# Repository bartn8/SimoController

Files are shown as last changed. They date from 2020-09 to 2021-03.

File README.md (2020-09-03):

# SimoController
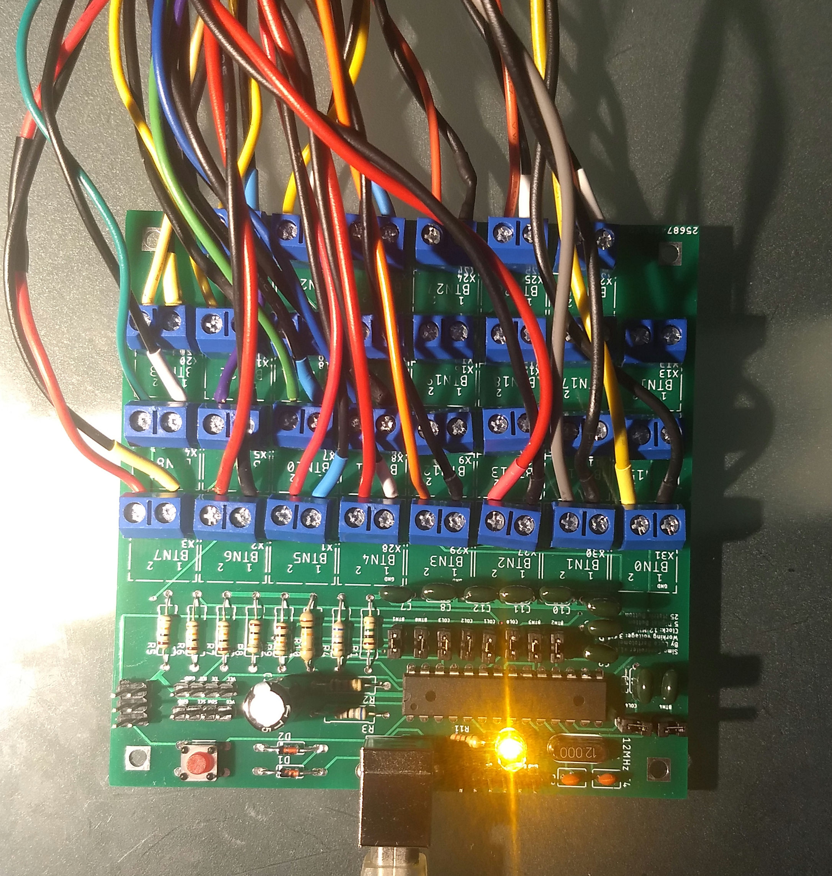
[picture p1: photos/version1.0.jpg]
Image of the Board

## An ATMEGA328P based gamepad controller

- **5 Digital buttons** (first two can be used as Analog pins)
- **25 Matrix buttons**
- **Gamepad HID Device**: four axis and 22 buttons for single gamepad or two axis and 11 buttons for double gamepad

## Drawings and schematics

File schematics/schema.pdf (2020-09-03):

# ATMEGA168-20PICSP

4u7

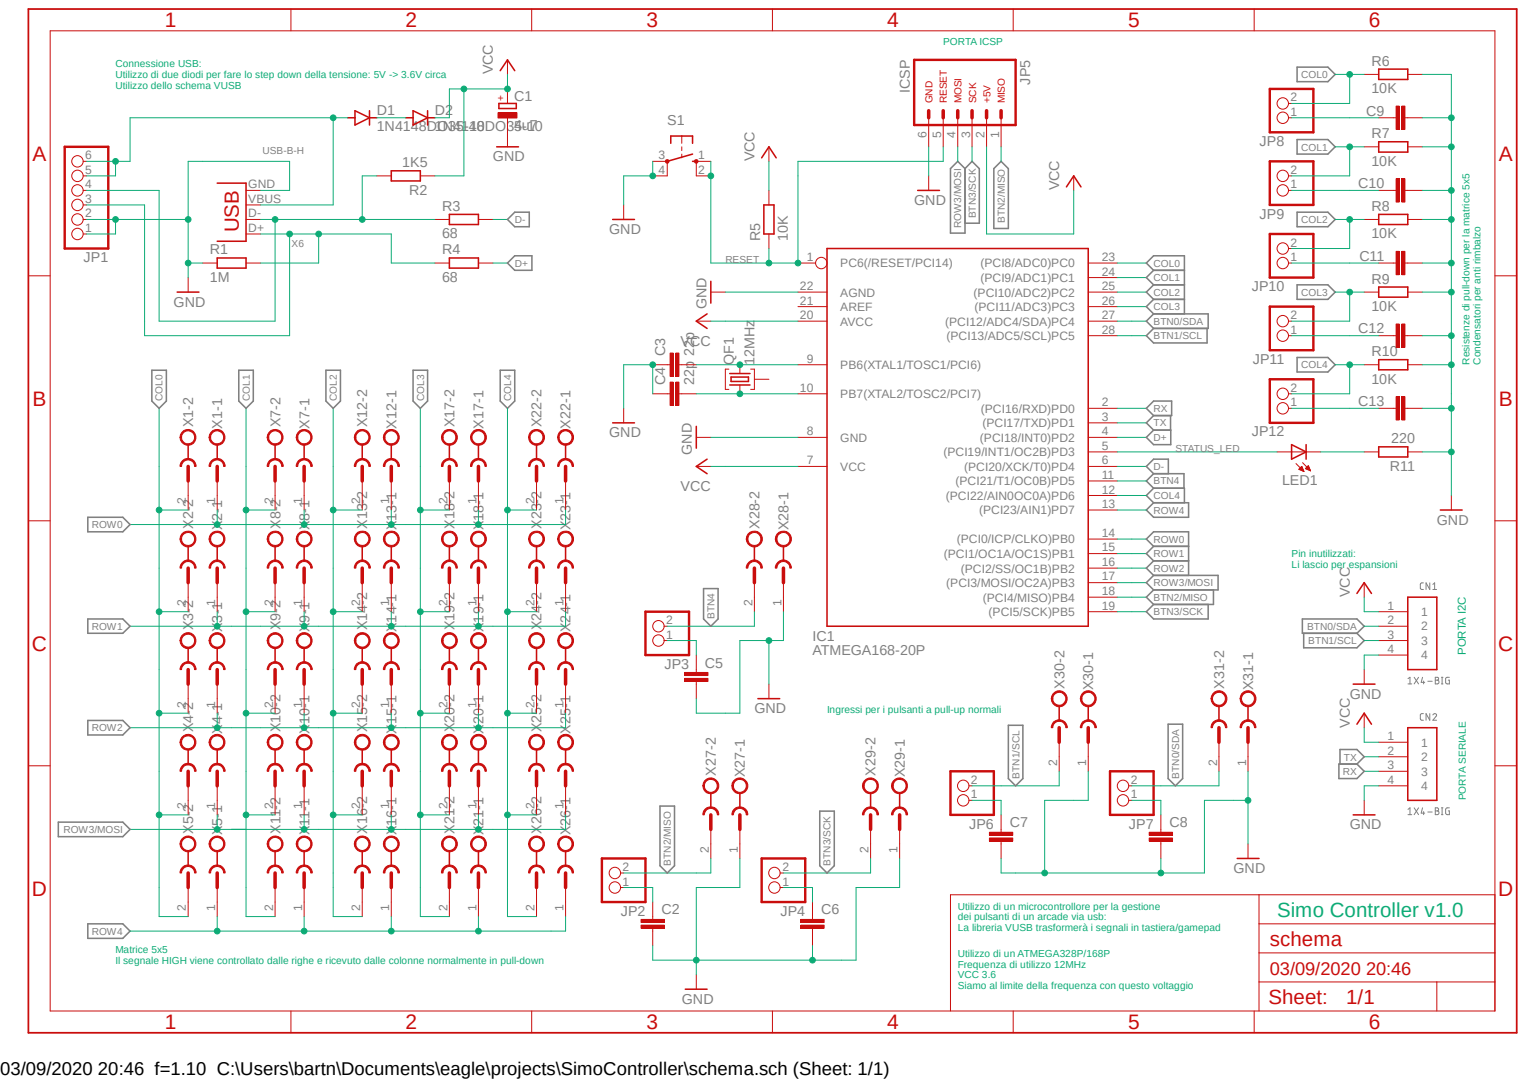
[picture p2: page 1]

Connessione USB:
Utilizzo di due diodi per fare lo step down della tensione: 5V -> 3.6V circa
Utilizzo dello schema VUSB

+GND RESET MOSI SCK +5V MISO USB

Pin inutilizzati:
Li lascio per espansioni

Ingressi per i pulsanti a pull-up normali

dei pulsanti di un arcade via usb: Frequenza di utilizzo 12MHz VCC 3.6 Siamo al limite della frequenza con questo voltaggio | Simo Controller v1.0 Utilizzo di un microcontrollore per la gestione

Sheet: 1/1

03/09/2020 20:46 f=1.10 C:\Users\bartn\Documents\eagle\projects\SimoController\schema.sch (Sheet: 1/1)

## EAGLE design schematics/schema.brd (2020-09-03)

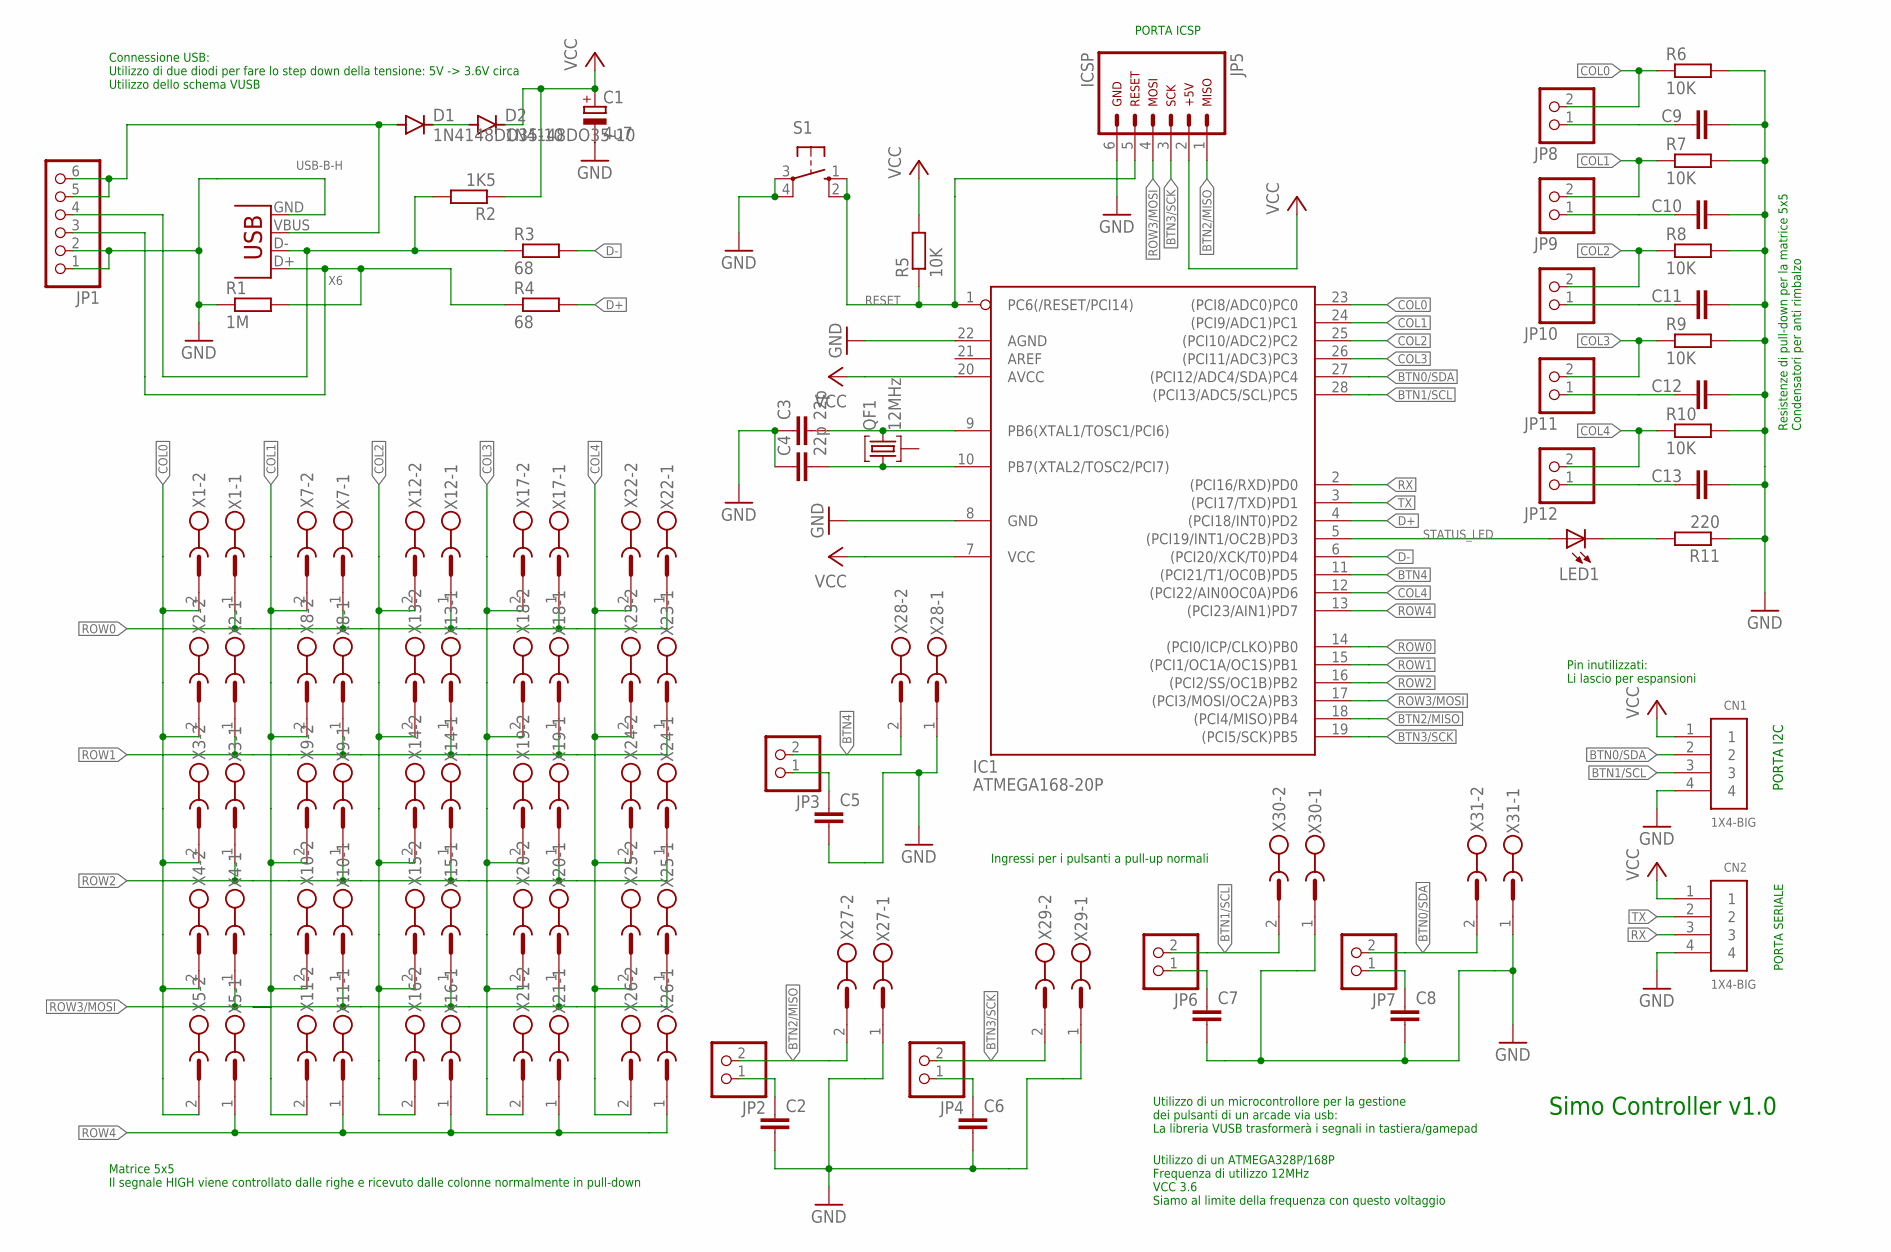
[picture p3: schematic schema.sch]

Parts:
C1: 4u7; E5-6
C2, C5, C6, C7, C8, C9, C10, C11, C12, C13: C-EU050-024X044; C050-024X044
C3, C4: 22p; C025-030X050
CN1, CN2: 1X4-BIG; 1X04-BIG
D1, D2: 1N4148DO35-10; DO35-10
IC1: ATMEGA168-20P; DIL28-3
JP1: PINHD-1X6; 1X06
JP2, JP3, JP4, JP6, JP7, JP8, JP9, JP10, JP11, JP12: PINHD-1X2; 1X02
JP5: ARDUINO_CONN-ICSP; CONN-2X03
LED1: LED3MM
QF1: 12MHz; HC49U
R1: 1M; 0309/12
R2: 1K5; 0309/12
R3, R4: 68; 0309/12
R5, R6, R7, R8, R9, R10: 10K; 0309/12
R11: 220; 0204/7
S1: 10-XX; B3F-10XX
X1, X2, X3, X4, X5, X7, X8, X9, X10, X11, X12, X13, X14, X15, X16, X17, X18, X19, X20, X21, X22, X23, X24, X25, X26, X27, X28, X29, X30, X31: MSTBV2
X6: USB-B-H

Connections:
BTN0/SDA: CN1.2, IC1.27 ((PCI12/ADC4/SDA)PC4), JP7.2, X31.2
BTN1/SCL: CN1.3, IC1.28 ((PCI13/ADC5/SCL)PC5), JP6.2, X30.2
BTN2/MISO: IC1.18 ((PCI4/MISO)PB4), JP2.2, JP5.1, X27.2
BTN3/SCK: IC1.19 ((PCI5/SCK)PB5), JP4.2, JP5.3, X29.2
BTN4: IC1.11 ((PCI21/T1/OC0B)PD5), JP3.2, X28.2
COL0: IC1.23 ((PCI8/ADC0)PC0), JP8.2, R6.1, X1.2, X2.2, X3.2, X4.2, X5.2
COL1: IC1.24 ((PCI9/ADC1)PC1), JP9.2, R7.1, X7.2, X8.2, X9.2, X10.2, X11.2
COL2: IC1.25 ((PCI10/ADC2)PC2), JP10.2, R8.1, X12.2, X13.2, X14.2, X15.2, X16.2
COL3: IC1.26 ((PCI11/ADC3)PC3), JP11.2, R9.1, X17.2, X18.2, X19.2, X20.2, X21.2
COL4: IC1.12 ((PCI22/AIN0OC0A)PD6), JP12.2, R10.1, X22.2, X23.2, X24.2, X25.2, X26.2
D+: IC1.4 ((PCI18/INT0)PD2), R4.2
D-: IC1.6 ((PCI20/XCK/T0)PD4), R3.2
GND: C1.-, C2.2, C3.1, C4.1, C5.2, C6.2, C7.2, C8.2, C9.2, C10.2, C11.2, C12.2, C13.2, CN1.4, CN2.4, IC1.8 (GND), IC1.22 (AGND), JP1.1, JP1.2, JP5.6, R1.1, R6.2, R7.2, R8.2, R9.2, R10.2, R11.1, S1.3, S1.4 (P1), X6.GND, X27.1, X28.1, X29.1, X30.1, X31.1
unnamed: D1.A, JP1.5, JP1.6, X6.VBUS
unnamed: D1.C, D2.A
unnamed: JP1.3, R1.2, R4.1, X6.D+
unnamed: JP1.4, R2.2, R3.1, X6.D-
unnamed: C3.2, IC1.9 (PB6(XTAL1/TOSC1/PCI6)), QF1.3
unnamed: C4.2, IC1.10 (PB7(XTAL2/TOSC2/PCI7)), QF1.1
unnamed: C5.1, JP3.1
unnamed: C9.1, JP8.1
unnamed: C10.1, JP9.1
unnamed: C2.1, JP2.1
unnamed: C6.1, JP4.1
unnamed: C7.1, JP6.1
unnamed: C8.1, JP7.1
unnamed: C11.1, JP10.1
unnamed: C12.1, JP11.1
unnamed: C13.1, JP12.1
unnamed: LED1.K (C), R11.2
RESET: IC1.1 (PC6(/RESET/PCI14)), JP5.5, R5.1, S1.1 (S), S1.2 (S1)
ROW0: IC1.14 ((PCI0/ICP/CLKO)PB0), X1.1, X7.1, X12.1, X17.1, X22.1
ROW1: IC1.15 ((PCI1/OC1A/OC1S)PB1), X2.1, X8.1, X13.1, X18.1, X23.1
ROW2: IC1.16 ((PCI2/SS/OC1B)PB2), X3.1, X9.1, X14.1, X19.1, X24.1
ROW3/MOSI: IC1.17 ((PCI3/MOSI/OC2A)PB3), JP5.4, X4.1, X10.1, X15.1, X20.1, X25.1
ROW4: IC1.13 ((PCI23/AIN1)PD7), X5.1, X11.1, X16.1, X21.1, X26.1
RX: CN2.3, IC1.2 ((PCI16/RXD)PD0)
STATUS_LED: IC1.5 ((PCI19/INT1/OC2B)PD3), LED1.A
TX: CN2.2, IC1.3 ((PCI17/TXD)PD1)
VCC: C1.+, CN1.1, CN2.1, D2.C, IC1.7 (VCC), IC1.20 (AVCC), JP5.2, R2.1, R5.2

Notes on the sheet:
Connessione USB: Utilizzo di due diodi per fare lo step down della tensione: 5V -> 3.6V circa Utilizzo dello schema VUSB
PORTA ICSP
PORTA SERIALE
Resistenze di pull-down per la matrice 5x5 Condensatori per anti rimbalzo
Ingressi per i pulsanti a pull-up normali
Matrice 5x5 Il segnale HIGH viene controllato dalle righe e ricevuto dalle colonne normalmente in pull-down
Utilizzo di un ATMEGA328P/168P Frequenza di utilizzo 12MHz VCC 3.6 Siamo al limite della frequenza con questo voltaggio
Pin inutilizzati: Li lascio per espansioni
Simo Controller v1.0
Utilizzo di un microcontrollore per la gestione dei pulsanti di un arcade via usb: La libreria VUSB trasformerà i segnali in tastiera/gamepad
PORTA I2C

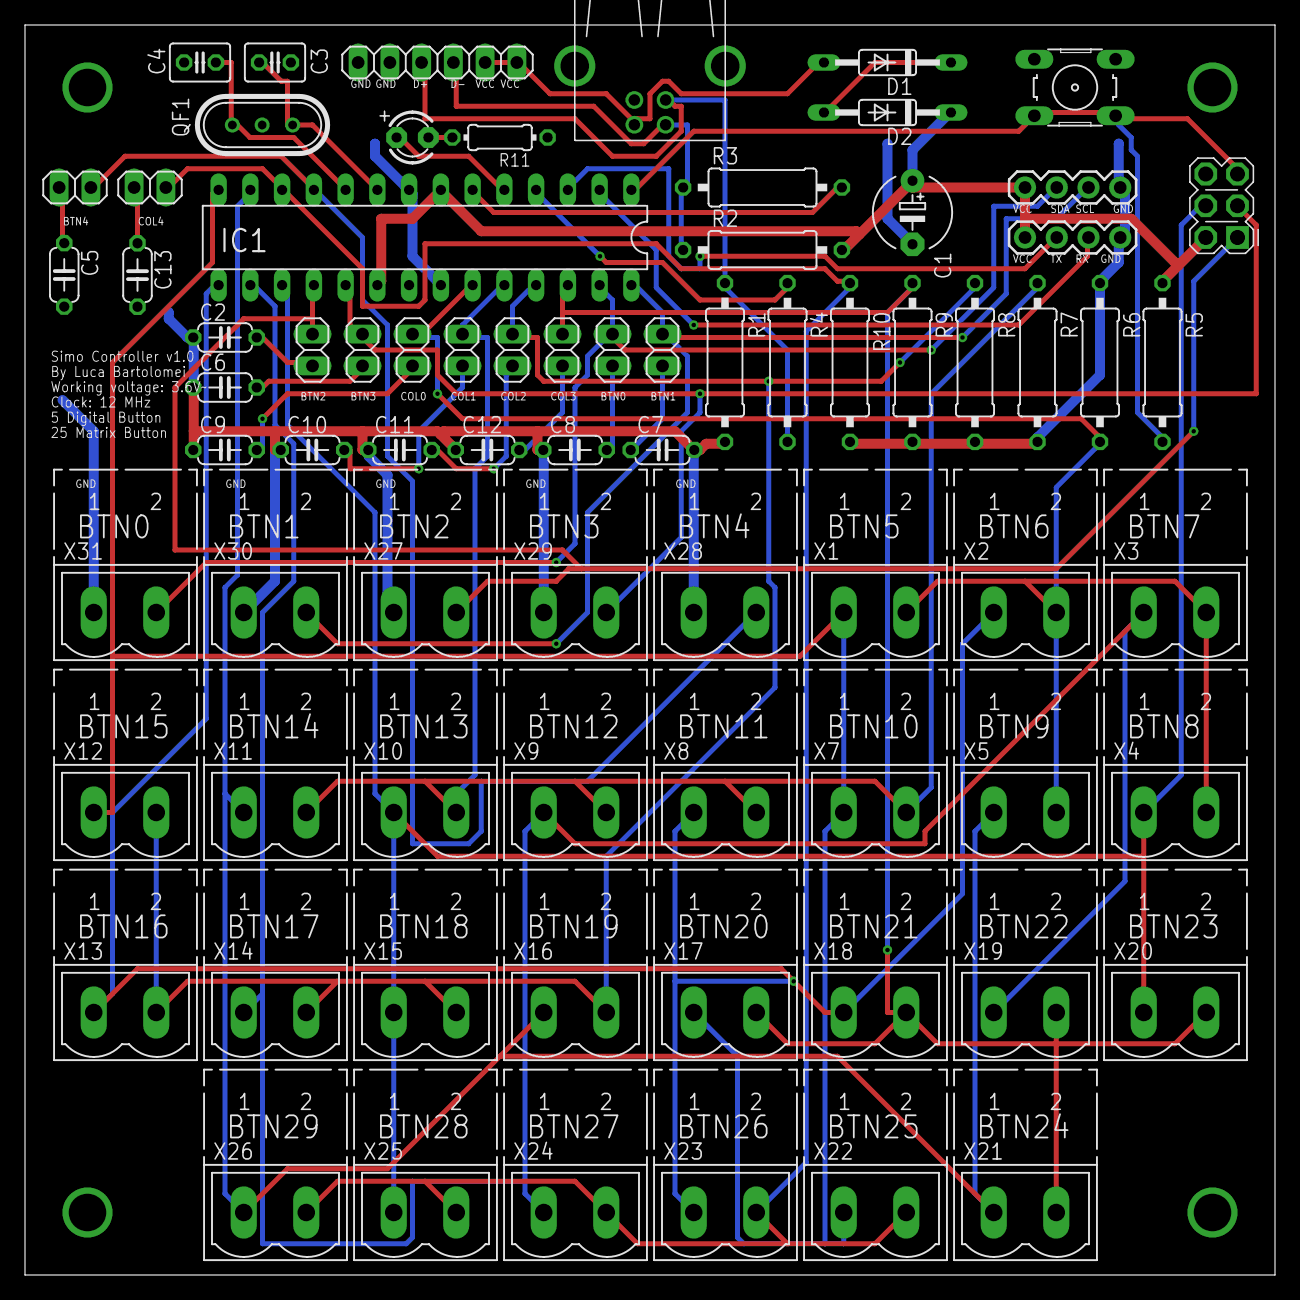
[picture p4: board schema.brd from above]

Board: 2 copper layers, 100.0 x 100.0 mm, 75 parts (0 on the bottom side), 40 nets.

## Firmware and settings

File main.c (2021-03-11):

/*
 * SimoController.c
 *
 * Created: 15/03/2020 20:32:37
 * Author : Luca Bartolomei <bartn8@hotmail.it>
 */ 

#ifndef F_CPU
#define F_CPU 12000000UL // 12 MHz clock speed
#endif

#include <avr/io.h>
#include <avr/interrupt.h>
#include <avr/wdt.h>
#include <avr/eeprom.h>
#include <util/delay.h>

#include <avr/pgmspace.h>   /* required by usbdrv.h */
#include "usbdrv/usbdrv.h"

#include "joyreader.h"


//https://eleccelerator.com/tutorial-about-usb-hid-report-descriptors/

// ************************
// *** USB HID ROUTINES ***
// ************************

//https://eleccelerator.com/tutorial-about-usb-hid-report-descriptors/

//100
const PROGMEM char usbHidReportDescriptor[USB_CFG_HID_REPORT_DESCRIPTOR_LENGTH] = {
    0x05, 0x01,                    // USAGE_PAGE (Generic Desktop)
    0x09, 0x05,                    // USAGE (Game Pad)
    0xa1, 0x01,                    // COLLECTION (Application)
    0xa1, 0x00,                    //   COLLECTION (Physical)
    0x85, 0x01,                    //     REPORT_ID (1)
    0x05, 0x09,                    //     USAGE_PAGE (Button)
    0x19, 0x01,                    //     USAGE_MINIMUM (Button 1)
    0x29, 0x0b,                    //     USAGE_MAXIMUM (Button 11)
    0x15, 0x00,                    //     LOGICAL_MINIMUM (0)
    0x25, 0x01,                    //     LOGICAL_MAXIMUM (1)
    0x95, 0x0b,                    //     REPORT_COUNT (11)
    0x75, 0x01,                    //     REPORT_SIZE (1)
    0x81, 0x02,                    //     INPUT (Data,Var,Abs)
    0x75, 0x05,                    //     REPORT_SIZE (5)
    0x95, 0x01,                    //     REPORT_COUNT (1)
    0x81, 0x03,                    //     INPUT (Cnst,Var,Abs)
    0x05, 0x01,                    //     USAGE_PAGE (Generic Desktop)
    0x09, 0x30,                    //     USAGE (X)
    0x09, 0x31,                    //     USAGE (Y)
    0x15, 0x81,                    //     LOGICAL_MINIMUM (-127)
    0x25, 0x7f,                    //     LOGICAL_MAXIMUM (127)
    0x75, 0x08,                    //     REPORT_SIZE (8)
    0x95, 0x02,                    //     REPORT_COUNT (2)
    0x81, 0x02,                    //     INPUT (Data,Var,Abs)
    0xc0,                          //   END_COLLECTION
    0xc0,                          // END_COLLECTION
    0x05, 0x01,                    // USAGE_PAGE (Generic Desktop)
    0x09, 0x05,                    // USAGE (Game Pad)
    0xa1, 0x01,                    // COLLECTION (Application)
    0xa1, 0x00,                    //   COLLECTION (Physical)
    0x85, 0x02,                    //     REPORT_ID (2)
    0x05, 0x09,                    //     USAGE_PAGE (Button)
    0x19, 0x0c,                    //     USAGE_MINIMUM (Button 12)
    0x29, 0x16,                    //     USAGE_MAXIMUM (Button 22)
    0x15, 0x00,                    //     LOGICAL_MINIMUM (0)
    0x25, 0x01,                    //     LOGICAL_MAXIMUM (1)
    0x95, 0x0b,                    //     REPORT_COUNT (11)
    0x75, 0x01,                    //     REPORT_SIZE (1)
    0x81, 0x02,                    //     INPUT (Data,Var,Abs)
    0x75, 0x05,                    //     REPORT_SIZE (5)
    0x95, 0x01,                    //     REPORT_COUNT (1)
    0x81, 0x03,                    //     INPUT (Cnst,Var,Abs)
    0x05, 0x01,                    //     USAGE_PAGE (Generic Desktop)
    0x09, 0x32,                    //     USAGE (Z)
    0x09, 0x33,                    //     USAGE (Rx)
    0x15, 0x81,                    //     LOGICAL_MINIMUM (-127)
    0x25, 0x7f,                    //     LOGICAL_MAXIMUM (127)
    0x75, 0x08,                    //     REPORT_SIZE (8)
    0x95, 0x02,                    //     REPORT_COUNT (2)
    0x81, 0x02,                    //     INPUT (Data,Var,Abs)
    0xc0,                          //   END_COLLECTION
    0xc0                           // END_COLLECTION
};

typedef struct
{
	uint8_t reportID;
	uint16_t buttons;
	int8_t x;
	int8_t y;
} gamepad_report_t;

static uint8_t* joyreader_report;

static uint8_t idle_rate = 500 / 4; // see HID1_11.pdf sect 7.2.4
static uint8_t protocol_version = 0; // see HID1_11.pdf sect 7.2.6

static gamepad_report_t gamepad_report_1;
static gamepad_report_t gamepad_report_2;

/************************************************************************/
/* Build a USB Report with two XY Axis and 22 buttons.                  */
/************************************************************************/
static void buildReport(void){
	//Axis reading from report.
	
	if(joyreader_report[JOYREADER_P_MATRIX_17] == JOYREADER_BTN_DOWN)
		gamepad_report_1.y = 127;
	else if(joyreader_report[JOYREADER_P_MATRIX_18] == JOYREADER_BTN_DOWN)
		gamepad_report_1.y = -127;
	else
		gamepad_report_1.y = 0;
	
	if(joyreader_report[JOYREADER_P_MATRIX_19] == JOYREADER_BTN_DOWN)
		gamepad_report_1.x = 127;
	else if(joyreader_report[JOYREADER_P_MATRIX_20] == JOYREADER_BTN_DOWN)
		gamepad_report_1.x = -127;
	else
		gamepad_report_1.x = 0;
	
	if(joyreader_report[JOYREADER_P_MATRIX_21] == JOYREADER_BTN_DOWN)
		gamepad_report_2.y = 127;
	else if(joyreader_report[JOYREADER_P_MATRIX_22] == JOYREADER_BTN_DOWN)
		gamepad_report_2.y = -127;
	else
		gamepad_report_2.y = 0;
	
	if(joyreader_report[JOYREADER_P_MATRIX_23] == JOYREADER_BTN_DOWN)
		gamepad_report_2.x = 127;
	else if(joyreader_report[JOYREADER_P_MATRIX_24] == JOYREADER_BTN_DOWN)
		gamepad_report_2.x = -127;
	else
		gamepad_report_2.x = 0;
	
	//Report ID setter
	gamepad_report_1.reportID = 1;
	gamepad_report_2.reportID = 2;
	
	//Button state reset.
	gamepad_report_1.buttons = 0x0000;
	gamepad_report_2.buttons = 0x0000;
	
	//Buttons reading from report.
	
	if(joyreader_report[JOYREADER_P_DIGITAL_0] == JOYREADER_BTN_DOWN)
		gamepad_report_1.buttons |= (uint16_t)1;
	
	if(joyreader_report[JOYREADER_P_DIGITAL_1] == JOYREADER_BTN_DOWN)
		gamepad_report_1.buttons |= (uint16_t)1 << 1;
		
	if(joyreader_report[JOYREADER_P_MATRIX_0] == JOYREADER_BTN_DOWN)
		gamepad_report_1.buttons |= (uint16_t)1 << 2;
		
	if(joyreader_report[JOYREADER_P_MATRIX_1] == JOYREADER_BTN_DOWN)
		gamepad_report_1.buttons |= (uint16_t)1 << 3;
	
	if(joyreader_report[JOYREADER_P_MATRIX_2] == JOYREADER_BTN_DOWN)
		gamepad_report_1.buttons |= (uint16_t)1 << 4;
		
	if(joyreader_report[JOYREADER_P_MATRIX_3] == JOYREADER_BTN_DOWN)
		gamepad_report_1.buttons |= (uint16_t)1 << 5;
	
	if(joyreader_report[JOYREADER_P_MATRIX_4] == JOYREADER_BTN_DOWN)
		gamepad_report_1.buttons |= (uint16_t)1 << 6;
	
	if(joyreader_report[JOYREADER_P_MATRIX_5] == JOYREADER_BTN_DOWN)
		gamepad_report_1.buttons |= (uint16_t)1 << 7;
	
	if(joyreader_report[JOYREADER_P_MATRIX_6] == JOYREADER_BTN_DOWN)
		gamepad_report_1.buttons |= (uint16_t)1 << 8;
		
	if(joyreader_report[JOYREADER_P_MATRIX_7] == JOYREADER_BTN_DOWN)
		gamepad_report_1.buttons |= (uint16_t)1 << 9;
		
	if(joyreader_report[JOYREADER_P_MATRIX_8] == JOYREADER_BTN_DOWN)
		gamepad_report_1.buttons |= (uint16_t)1 << 10;
	
	if(joyreader_report[JOYREADER_P_DIGITAL_2] == JOYREADER_BTN_DOWN)
		gamepad_report_2.buttons |= (uint16_t)1;
	
	if(joyreader_report[JOYREADER_P_DIGITAL_3] == JOYREADER_BTN_DOWN)
		gamepad_report_2.buttons |= (uint16_t)1 << 1;
		
	if(joyreader_report[JOYREADER_P_DIGITAL_4] == JOYREADER_BTN_DOWN)
		gamepad_report_2.buttons |= (uint16_t)1 << 2;
			
	if(joyreader_report[JOYREADER_P_MATRIX_9] == JOYREADER_BTN_DOWN)
		gamepad_report_2.buttons |= (uint16_t)1 << 3;
	
	if(joyreader_report[JOYREADER_P_MATRIX_10] == JOYREADER_BTN_DOWN)
		gamepad_report_2.buttons |= (uint16_t)1 << 4;
		
	if(joyreader_report[JOYREADER_P_MATRIX_11] == JOYREADER_BTN_DOWN)
		gamepad_report_2.buttons |= (uint16_t)1 << 5;
	
	if(joyreader_report[JOYREADER_P_MATRIX_12] == JOYREADER_BTN_DOWN)
		gamepad_report_2.buttons |= (uint16_t)1 << 6;
	
	if(joyreader_report[JOYREADER_P_MATRIX_13] == JOYREADER_BTN_DOWN)
		gamepad_report_2.buttons |= (uint16_t)1 << 7;
	
	if(joyreader_report[JOYREADER_P_MATRIX_14] == JOYREADER_BTN_DOWN)
		gamepad_report_2.buttons |= (uint16_t)1 << 8;
		
	if(joyreader_report[JOYREADER_P_MATRIX_15] == JOYREADER_BTN_DOWN)
		gamepad_report_2.buttons |= (uint16_t)1 << 9;
		
	if(joyreader_report[JOYREADER_P_MATRIX_16] == JOYREADER_BTN_DOWN)
		gamepad_report_2.buttons |= (uint16_t)1 << 10;
	
}

usbMsgLen_t usbFunctionSetup(uint8_t data[8])
{
	// see HID1_11.pdf sect 7.2 and http://vusb.wikidot.com/driver-api
	usbRequest_t *rq = (void *)data;

	if ((rq->bmRequestType & USBRQ_TYPE_MASK) != USBRQ_TYPE_CLASS)
	return 0; // ignore request if it's not a class specific request

	// see HID1_11.pdf sect 7.2
	switch (rq->bRequest)
	{
		case USBRQ_HID_GET_IDLE:
		usbMsgPtr = (usbMsgPtr_t)&idle_rate; // send data starting from this byte
		return 1; // send 1 byte
		case USBRQ_HID_SET_IDLE:
		idle_rate = rq->wValue.bytes[1]; // read in idle rate
		return 0; // send nothing
		case USBRQ_HID_GET_PROTOCOL:
		usbMsgPtr = (usbMsgPtr_t)&protocol_version; // send data starting from this byte
		return 1; // send 1 byte
		case USBRQ_HID_SET_PROTOCOL:
		protocol_version = rq->wValue.bytes[1];
		return 0; // send nothing
		case USBRQ_HID_GET_REPORT:
		
			// check for report ID then send back report
			if (rq->wValue.bytes[0] == 1)
			{
				usbMsgPtr = (usbMsgPtr_t)&gamepad_report_1;
				return sizeof(gamepad_report_t);
			}
			else if (rq->wValue.bytes[0] == 2)
			{
				usbMsgPtr = (usbMsgPtr_t)&gamepad_report_2;
				return sizeof(gamepad_report_t);
			}
			else
			{
				return 0; // no such report, send nothing
			}
		
		case USBRQ_HID_SET_REPORT: // no "output" or "feature" implemented, so ignore
		return 0; // send nothing
		default: // do not understand data, ignore
		return 0; // send nothing
	}
}


// this function is used to guarantee that the data is sent to the computer once
void usbSendHidReport(uchar * data, uchar len)
{
	while(1)
	{
		if (usbInterruptIsReady())
		{
			//Watchdog reset is placed here to prevent idle state from USB interrput.
			wdt_reset();
			
			usbSetInterrupt(data, len);
			break;
		}
		
		usbPoll();
	}
}

int main(void) {	
	//joyreader_resetIO();
	
	//LED: Used only as ON state LED. If watchdog is trigged, the LED will shutdown for a while.
	DDRD |= (1<<PD3);
	PORTD ^= (1<<PD3);	//Toggle LED
	
	// timer is initialized, used to keep track of idle period
	//1024 Prescaler
	TCCR1B = _BV(CS12) | _BV(CS10); 
	
	joyreader_initButtons();
	
	//Initial Report
	uint8_t to_send = 1; // boolean, true for first time
	to_send |= joyreader_updateButtons(); 
 	joyreader_report = joyreader_getReport();
		 
 	buildReport();
		
	wdt_enable(WDTO_4S); // enable 1s watchdog timer

	usbInit();
	usbDeviceDisconnect(); // enforce re-enumeration
	
	for(uint8_t i = 0; i<250; i++) { // wait 500 ms
		wdt_reset(); // keep the watchdog happy
		_delay_ms(2);
	}
	
	usbDeviceConnect();
	
	sei(); // Enable interrupts after re-enumeration
		
	while(1) {
		usbPoll();
				
		/*
		 * this area is where you should set the movement
		 * and button values of the reports using the input
		 * method of your choice
		 *
		*/
 		
		to_send |= joyreader_updateButtons(); 
 		joyreader_report = joyreader_getReport();
 		buildReport();
		 
		if (to_send == 0 && (idle_rate != 0 && (TCNT1 > ((4 * (F_CPU / 1024000)) * idle_rate) || TCNT1 > 0x7FFF)))
		{// using idle rate
			 to_send = 1;
		}
		
		if (usbInterruptIsReady())
		{
			//Watchdog reset is placed here to prevent idle state from USB interrput.
			wdt_reset();
			
			if(to_send != 0){
				// send the data if needed
			
				usbSendHidReport((uchar *)&gamepad_report_1,  sizeof(gamepad_report_t));
				usbSendHidReport((uchar *)&gamepad_report_2,  sizeof(gamepad_report_t));
			
				TCNT1 = 0; // reset timer
			}
		}
					
		//Reset flag
		to_send = 0;
	}
	
	return 0;
}

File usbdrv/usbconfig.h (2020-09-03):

/* Name: usbconfig.h
 * Project: V-USB, virtual USB port for Atmel's(r) AVR(r) microcontrollers
 * Author: Christian Starkjohann
 * Creation Date: 2005-04-01
 * Tabsize: 4
 * Copyright: (c) 2005 by OBJECTIVE DEVELOPMENT Software GmbH
 * License: GNU GPL v2 (see License.txt), GNU GPL v3 or proprietary (CommercialLicense.txt)
 * This Revision: $Id$
 */

#ifndef __usbconfig_h_included__
#define __usbconfig_h_included__

#ifndef F_CPU
#define F_CPU 12000000UL // 12 MHz clock speed
#endif

/*
General Description:
This file is an example configuration (with inline documentation) for the USB
driver. It configures V-USB for USB D+ connected to Port D bit 2 (which is
also hardware interrupt 0 on many devices) and USB D- to Port D bit 4. You may
wire the lines to any other port, as long as D+ is also wired to INT0 (or any
other hardware interrupt, as long as it is the highest level interrupt, see
section at the end of this file).
*/

/* ---------------------------- Hardware Config ---------------------------- */

#define USB_CFG_IOPORTNAME      D
/* This is the port where the USB bus is connected. When you configure it to
 * "B", the registers PORTB, PINB and DDRB will be used.
 */
#define USB_CFG_DMINUS_BIT      4
/* This is the bit number in USB_CFG_IOPORT where the USB D- line is connected.
 * This may be any bit in the port.
 */
#define USB_CFG_DPLUS_BIT       2
/* This is the bit number in USB_CFG_IOPORT where the USB D+ line is connected.
 * This may be any bit in the port. Please note that D+ must also be connected
 * to interrupt pin INT0! [You can also use other interrupts, see section
 * "Optional MCU Description" below, or you can connect D- to the interrupt, as
 * it is required if you use the USB_COUNT_SOF feature. If you use D- for the
 * interrupt, the USB interrupt will also be triggered at Start-Of-Frame
 * markers every millisecond.]
 */
#define USB_CFG_CLOCK_KHZ       (F_CPU/1000)
/* Clock rate of the AVR in kHz. Legal values are 12000, 12800, 15000, 16000,
 * 16500, 18000 and 20000. The 12.8 MHz and 16.5 MHz versions of the code
 * require no crystal, they tolerate +/- 1% deviation from the nominal
 * frequency. All other rates require a precision of 2000 ppm and thus a
 * crystal!
 * Since F_CPU should be defined to your actual clock rate anyway, you should
 * not need to modify this setting.
 */
#define USB_CFG_CHECK_CRC       0
/* Define this to 1 if you want that the driver checks integrity of incoming
 * data packets (CRC checks). CRC checks cost quite a bit of code size and are
 * currently only available for 18 MHz crystal clock. You must choose
 * USB_CFG_CLOCK_KHZ = 18000 if you enable this option.
 */

/* ----------------------- Optional Hardware Config ------------------------ */

/* #define USB_CFG_PULLUP_IOPORTNAME   D */
/* If you connect the 1.5k pullup resistor from D- to a port pin instead of
 * V+, you can connect and disconnect the device from firmware by calling
 * the macros usbDeviceConnect() and usbDeviceDisconnect() (see usbdrv.h).
 * This constant defines the port on which the pullup resistor is connected.
 */
/* #define USB_CFG_PULLUP_BIT          4 */
/* This constant defines the bit number in USB_CFG_PULLUP_IOPORT (defined
 * above) where the 1.5k pullup resistor is connected. See description
 * above for details.
 */

/* --------------------------- Functional Range ---------------------------- */
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

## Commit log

2020-09-03 Inital commit
    Schematics and photo are missing
    [joyreader.c, main.c, usbconfig.h]
2020-09-03 Added schematics and photo
    [schema.brd, schema.sch]
2021-03-11 Bugfix (Not tested)
    Se si premono tutti i pulsanti contemporaneamente allora il dispositivo si resetta
    Provato a risolvere (non testato):
    - Watchdog time: 1sec -> 4sec
    - Riduzione finestra di accensione delle righe attraverso ottimizzazione (riduce il voltage drop)
    - Aumento del condensatore di VCC
    - Aumento delle resistenze di pull-down
    [joyreader.c, main.c]
